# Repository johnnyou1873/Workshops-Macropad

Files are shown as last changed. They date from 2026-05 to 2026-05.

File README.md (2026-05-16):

# Workshops-Macropad
A custom 6-key keyboard with rotary encoder, 3D-printed case with integrated plate mounting, and VIA firmware.

## Bill of Materials
### Required
 - 1x Seeed Studio XIAO RP2040
 - 6x MX hotswap sockets
 - 7x 1N4148 small signal diodes
 - 1x EC11 rotary encoder with push button
 - 4x M3x12 screws (support M3x8 - M3x14) (or the 3D printable pegs/rivets)

### Optional for RGB
 - 6x SK-6812 MINI-E reverse-mount RGB LEDs
 - 6x 100n 0805 decoupling capacitors
 - 2x 10k 0805 pull-up resistors
 - 1x BSS138 N-channel MOSFET

### Optional for GPIO
 - 4x 2.54mm pitch male right-angle pin headers

## Assembly Instructions (Basic)

1. 3D print the top case, bottom case, and knob. If not using screws, print the pegs/rivets. For the best results, print the top case and bottom case with 100% infill.
2. Solder the hotswap sockets and diodes, taking note of the polarity. These components belong on the side with the "mini macropad" text.
3. Solder the microcontroller, using pin headers to align the pads but not soldering the pin headers.
4. Solder the rotary encoder on the opposite side of the board as the rest of the components.
5. Press and hold the BOOT button on the microcontroller. Then, while still holding the button, plug in the microcontroller to a computer. The microcontroller should appear as a virtual USB storage device.
6. Upload the .uf2 firmware file to the microcontroller. The virtual USB storage device should disconnect once flashed.
7. Unplug and replug the USB cable.
8. Test that the keys work by inserting switches into the hotswap sockets and depressing them. The keys should type the numbers 1-6 by default.
9. Test that the rotary encoder works by rotating it and pressing it. The encoder should control volume when rotated and type the number 7 when pressed.
10. Unplug the USB cable.
11. Insert the completed PCB into the bottom case, slotting in the USB conector first.
12. Place the top case on top of the bottom case.
13. Secure the bottom case to the top case with the M3x12 screws or the printable pegs/rivets.
14. Insert the switches into the top case. The switches should securely slot into the hotswap sockets.
15. Attach the keycaps and knob to the key switches and rotary encoder.
16. Connect the USB cable.
17. Open the [VIA app](https://www.usevia.app/).
18. Go to the "Settings" tab and enable "Show Design tab".
19. Go to the "Design" tab and upload the .json file.
20. Go to the "Configure" tab. After authorizing the device, the macropad is now configurable!

### Notes

On MacOS, plugging in the macropad for the first time after programming may trigger a message about keyboard layout. Because the macropad has a nonstandard layout, this message can be ignored. The keyboard should work with the configuration set with VIA.

RGB is implemented on the PCB but has not been tested.

To leverage the GPIO pins fully, custom firmware is needed.

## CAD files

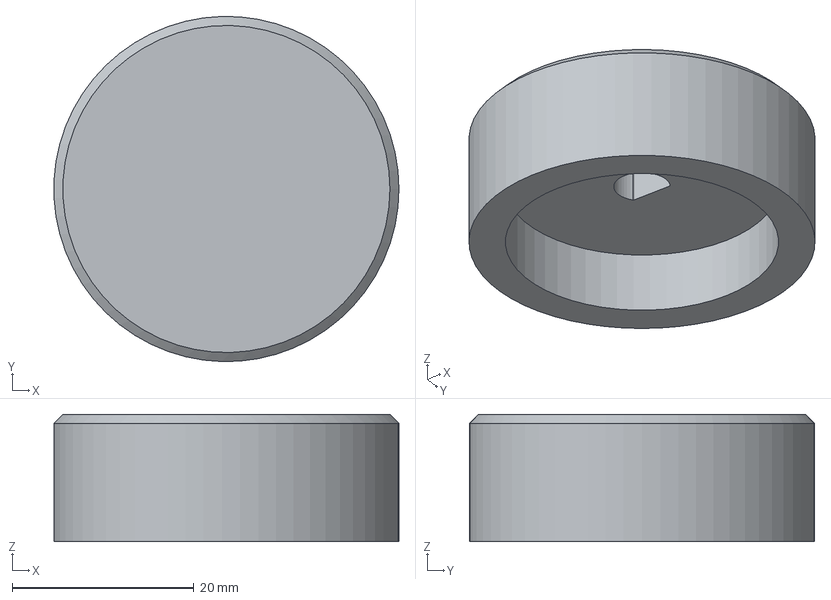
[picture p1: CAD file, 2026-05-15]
case/knob_short.step
38.0 x 38.0 x 14.0 mm

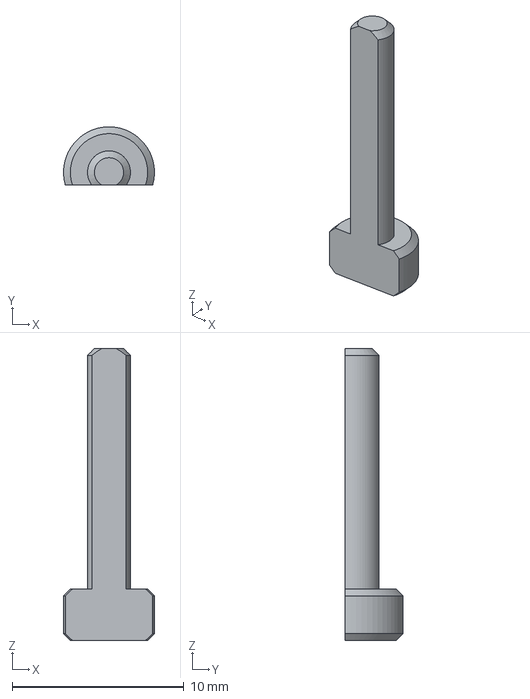
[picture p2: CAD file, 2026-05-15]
case/peg.step
5.30 x 3.40 x 17.0 mm

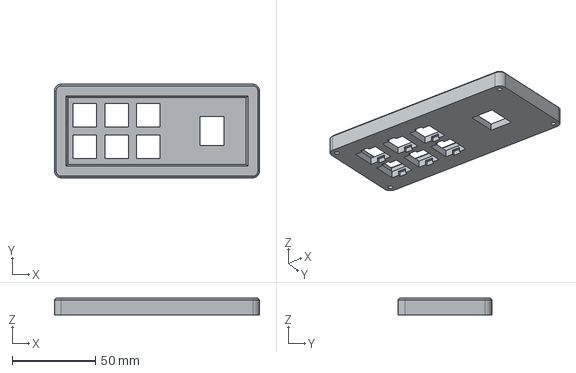
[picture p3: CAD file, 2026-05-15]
case/case_top.step
122.8 x 56.1 x 10.00 mm

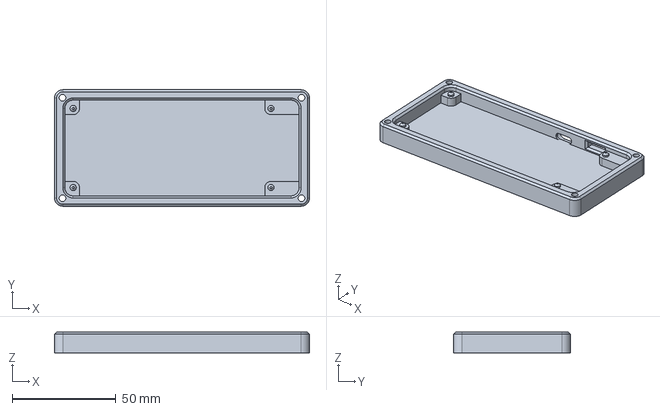
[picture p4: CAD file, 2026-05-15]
case/case.FCStd
122.8 x 56.1 x 10.0 mm

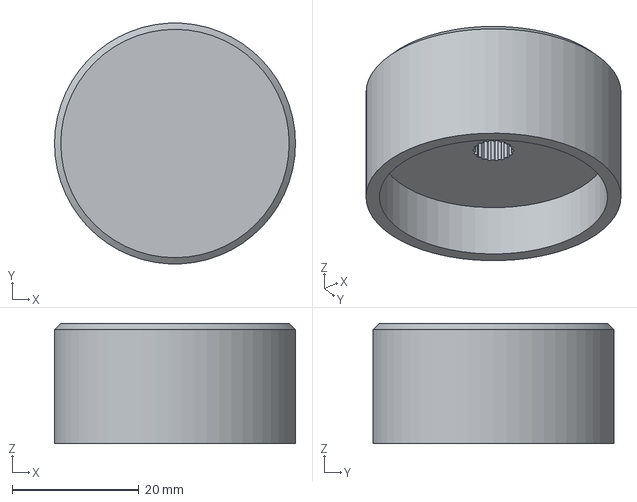
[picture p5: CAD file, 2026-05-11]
case/knob.step
38.1 x 38.0 x 19.0 mm

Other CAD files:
case/case_bottom.step
case/case.3mf
case/knob.FCStd
case/knob_short.3mf
case/knob_short.FCStd
case/peg.3mf
case/peg.FCStd

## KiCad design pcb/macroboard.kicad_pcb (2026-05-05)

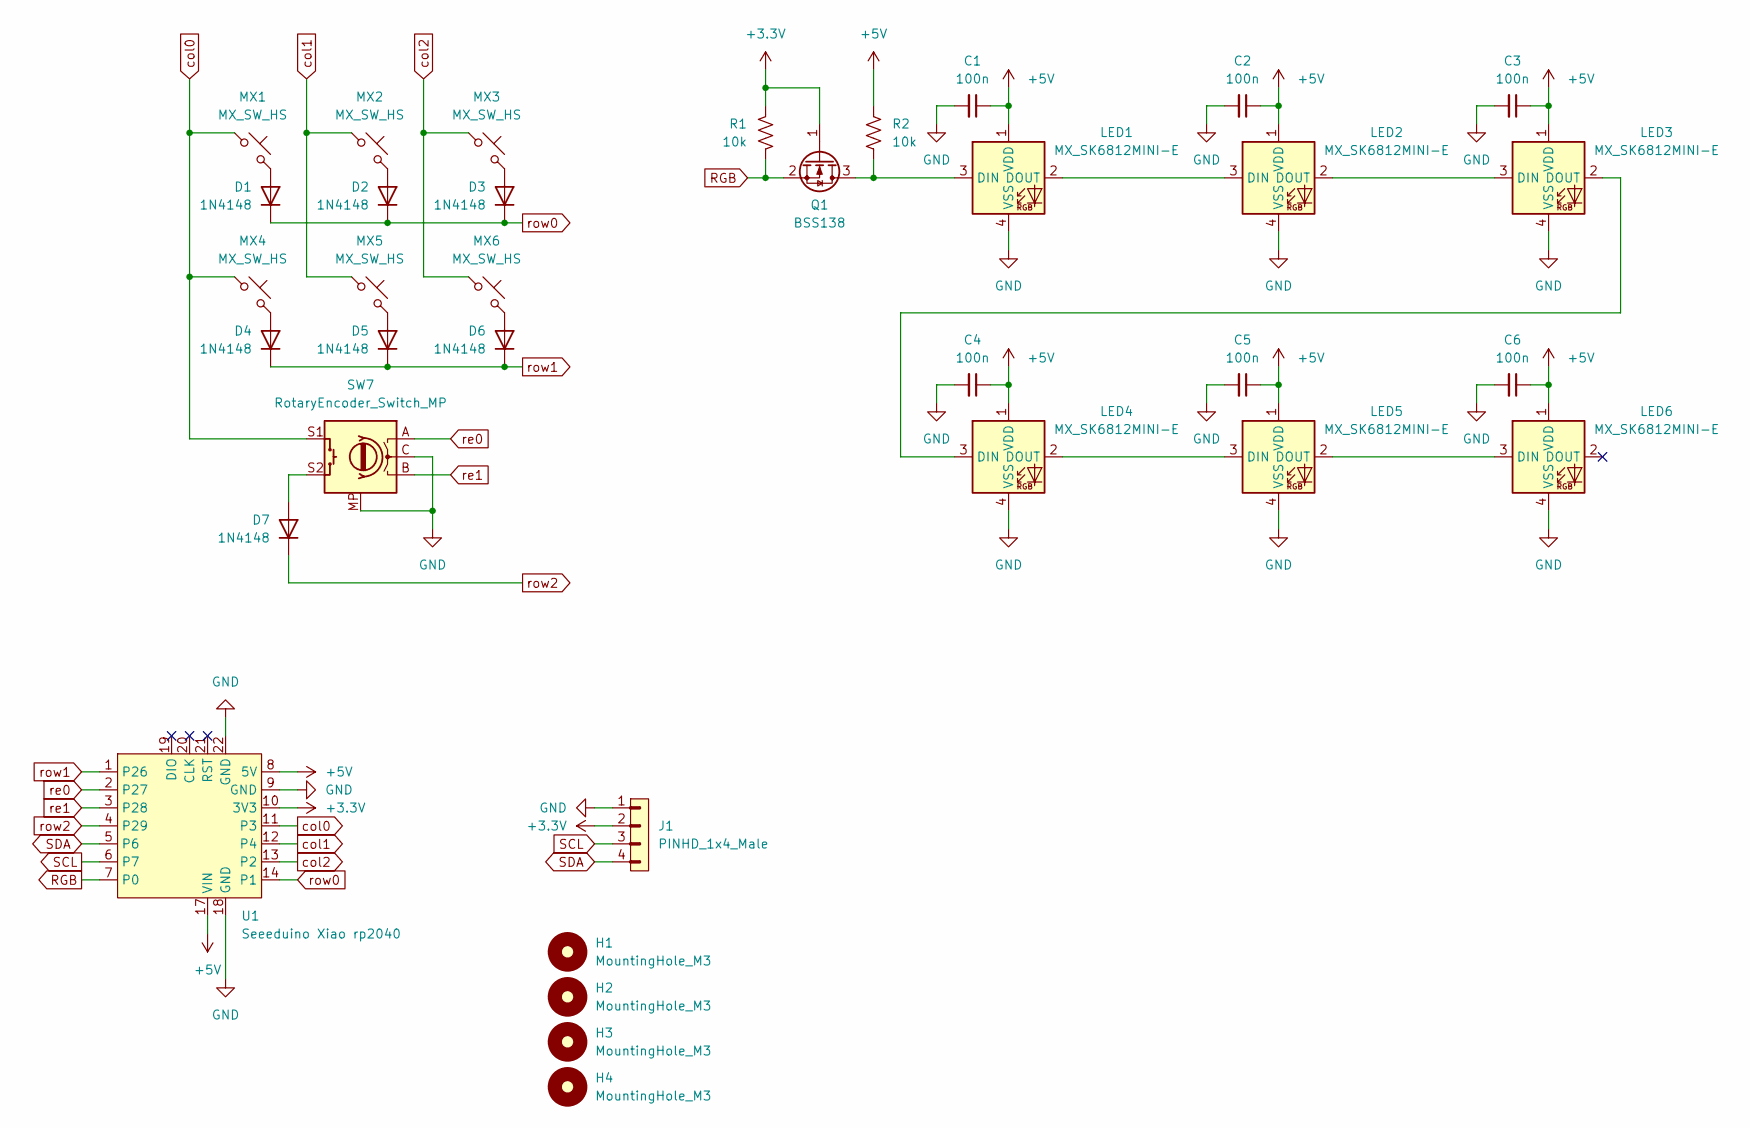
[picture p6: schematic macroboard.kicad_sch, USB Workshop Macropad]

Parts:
C1, C2, C3, C4, C5, C6: 100n; C_0805_2012Metric_Pad1.18x1.45mm_HandSolder
D1, D2, D3, D4, D5, D6, D7: 1N4148; D_DO-35_SOD27_P7.62mm_Horizontal_Hybrid
H1, H2, H3, H4: MountingHole_M3; MountingHole_3.2mm_M3_Pad
J1: PINHD_1x4_Male; PinHeader_1x04_P2.54mm_Horizontal
LED1, LED2, LED3, LED4, LED5, LED6: MX_SK6812MINI-E; LED_MX_6028R
MX1, MX2, MX3, MX4, MX5, MX6: MX_SW_HS; SW_MX_HS_CPG151101S11_1u
Q1: BSS138; SOT-23
R1, R2: 10k; R_0805_2012Metric_Pad1.20x1.40mm_HandSolder
SW7: RotaryEncoder_Switch_MP; ROT_Alps_EC11E-Switch
U1: Seeeduino Xiao rp2040; Xiao_rp2040_ACH

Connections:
+3.3V: J1.2, Q1.1 (G), R1.2, U1.10 (3V3)
+5V: C1.1, C2.1, C3.1, C4.1, C5.1, C6.1, LED1.1 (VDD), LED2.1 (VDD), LED3.1 (VDD), LED4.1 (VDD), LED5.1 (VDD), LED6.1 (VDD), R2.2, U1.8 (5V), U1.17 (VIN)
GND: C1.2, C2.2, C3.2, C4.2, C5.2, C6.2, J1.1, LED1.4 (VSS), LED2.4 (VSS), LED3.4 (VSS), LED4.4 (VSS), LED5.4 (VSS), LED6.4 (VSS), SW7.C, SW7.MP, U1.9 (GND), U1.18 (GND), U1.22 (GND)
unnamed: D1.2 (A), MX1.2
unnamed: D2.2 (A), MX2.2
unnamed: D3.2 (A), MX3.2
unnamed: D4.2 (A), MX4.2
unnamed: D5.2 (A), MX5.2
unnamed: D6.2 (A), MX6.2
unnamed: D7.2 (A), SW7.S2
unnamed: LED1.3 (DIN), Q1.3 (D), R2.1
unnamed: LED1.2 (DOUT), LED2.3 (DIN)
unnamed: LED2.2 (DOUT), LED3.3 (DIN)
unnamed: LED3.2 (DOUT), LED4.3 (DIN)
unnamed: LED4.2 (DOUT), LED5.3 (DIN)
unnamed: LED5.2 (DOUT), LED6.3 (DIN)
RGB: Q1.2 (S), R1.1, U1.7 (P0)
SCL: J1.3, U1.6 (P7)
SDA: J1.4, U1.5 (P6)
col0: MX1.1, MX4.1, SW7.S1, U1.11 (P3)
col1: MX2.1, MX5.1, U1.12 (P4)
col2: MX3.1, MX6.1, U1.13 (P2)
re0: SW7.A, U1.2 (P27)
re1: SW7.B, U1.3 (P28)
row0: D1.1 (K), D2.1 (K), D3.1 (K), U1.14 (P1)
row1: D4.1 (K), D5.1 (K), D6.1 (K), U1.1 (P26)
row2: D7.1 (K), U1.4 (P29)

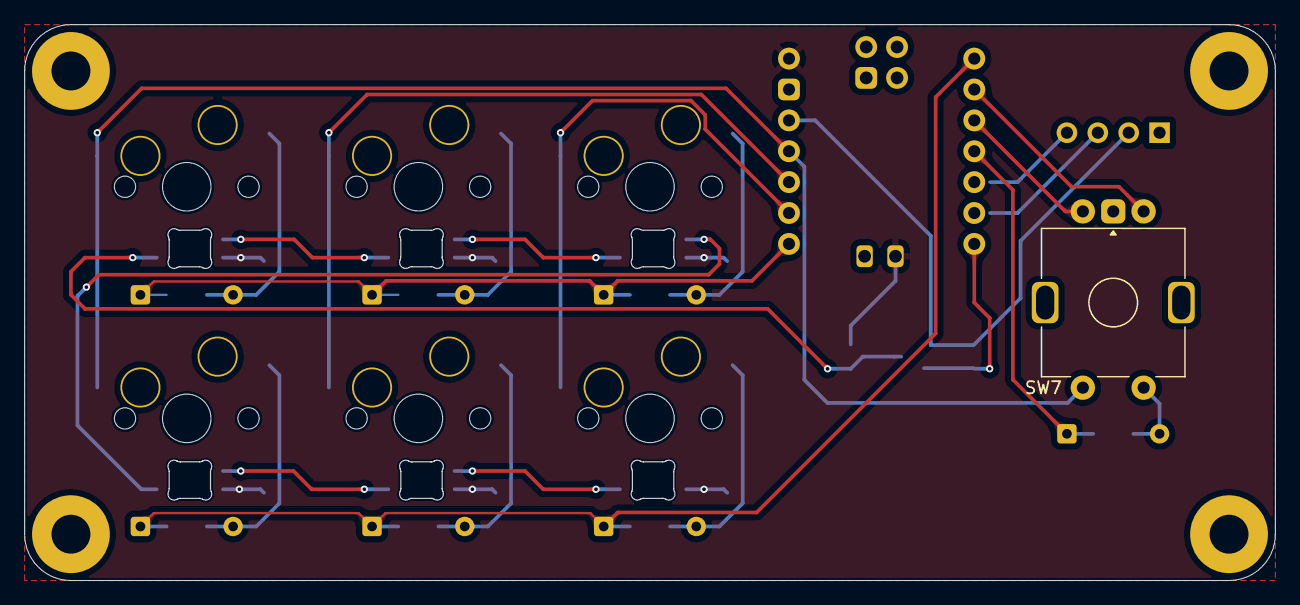
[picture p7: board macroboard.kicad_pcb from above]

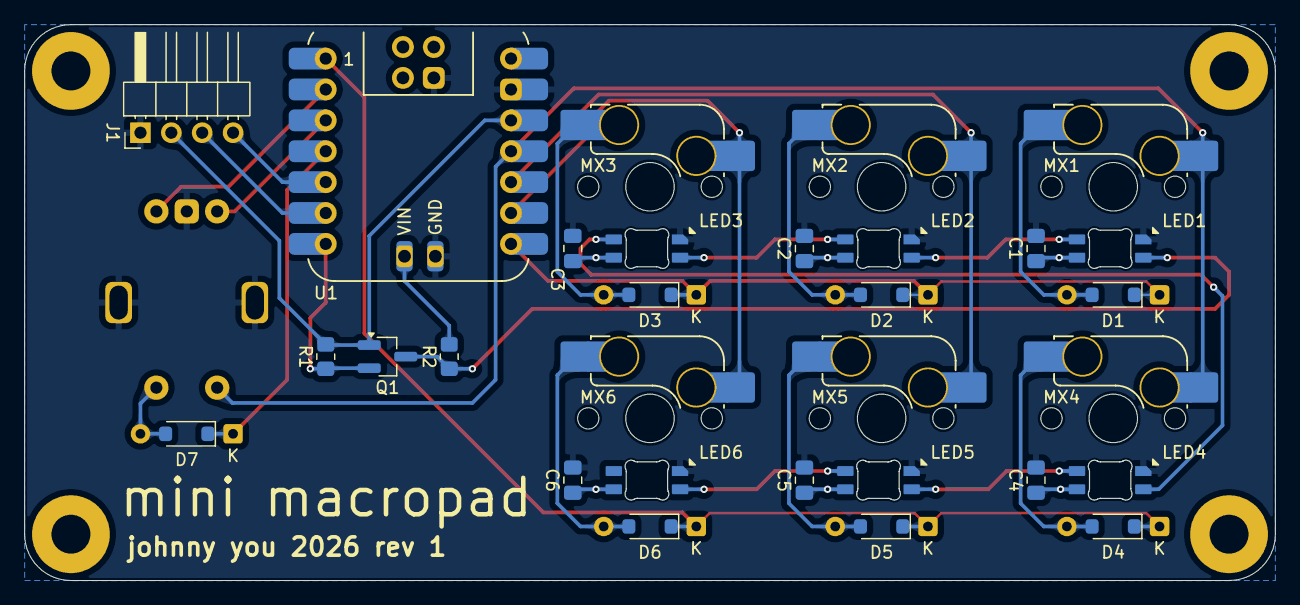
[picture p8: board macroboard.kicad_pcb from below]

Board: 2 copper layers, 102.9 x 45.7 mm, 35 parts (30 on the bottom side), 27 nets.

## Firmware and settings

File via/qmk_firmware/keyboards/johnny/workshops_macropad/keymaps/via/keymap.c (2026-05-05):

#include QMK_KEYBOARD_H

const uint16_t PROGMEM keymaps[][MATRIX_ROWS][MATRIX_COLS] = {
    [0] = LAYOUT(
        KC_1,    KC_2,    KC_3,
        KC_4,    KC_5,    KC_6,
        KC_7
    ),
    [1] = LAYOUT(
        _______, _______, _______,
        _______, _______, _______,
        _______
    ),
    [2] = LAYOUT(
        _______, _______, _______,
        _______, _______, _______,
        _______
    ),
    [3] = LAYOUT(
        _______, _______, _______,
        _______, _______, _______,
        _______
    )
};

#if defined(ENCODER_MAP_ENABLE)
const uint16_t PROGMEM encoder_map[][NUM_ENCODERS][NUM_DIRECTIONS] = {
    [0] = { ENCODER_CCW_CW(KC_VOLD, KC_VOLU) },
    [1] = { ENCODER_CCW_CW(_______, _______) },
    [2] = { ENCODER_CCW_CW(_______, _______) },
    [3] = { ENCODER_CCW_CW(_______, _______) }
};
#endif

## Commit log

2026-05-05 Update README with RGB notes and bill of materials
    Added notes on RGB implementation and a detailed bill of materials.
2026-05-05 Added QMK source files and organized CAD files.
    [bottom_case-Body.3mf, bottom_case-Body001.3mf, bottom_case.3mf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]
2026-05-08 Update VIA JSON to fully support rotary encoder.
2026-05-11 Clean up 3D files
    [bottom_case-Body.3mf, bottom_case-Body001.3mf, bottom_case.3mf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]
2026-05-15 Add printable peg to sub M3 screw
    [case.3mf, case.FCStd, case_top.step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]
2026-05-16 Update README with assembly instructions and BOM details
    Added assembly instructions and additional details to the Bill of Materials.
